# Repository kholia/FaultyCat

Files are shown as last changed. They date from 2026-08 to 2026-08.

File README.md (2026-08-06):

# Faulty Cat

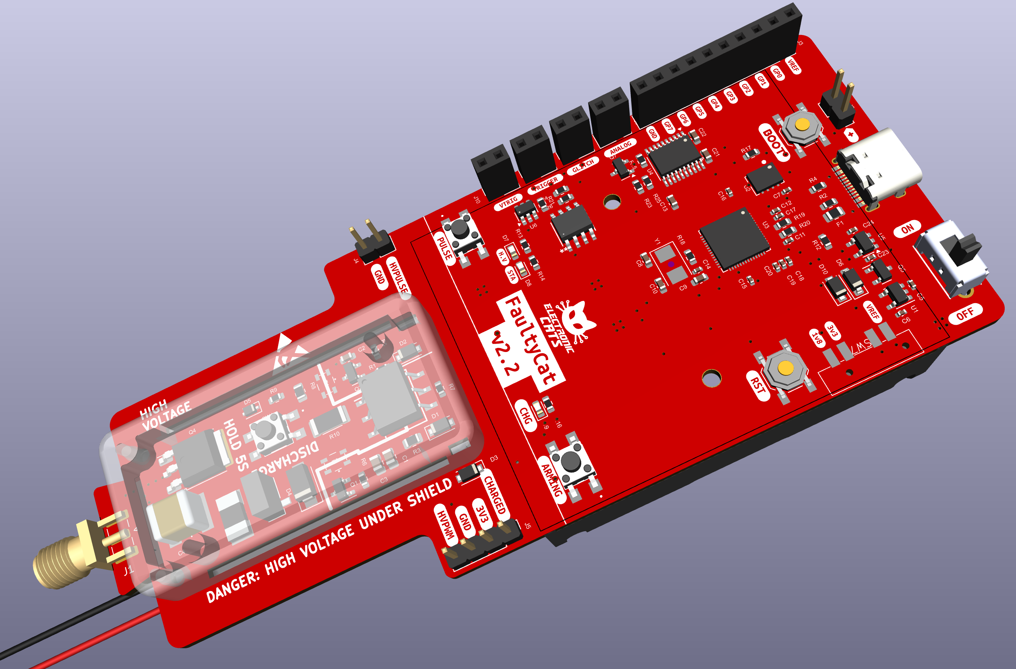
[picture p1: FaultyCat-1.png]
Fault Cat Render 1


> ## Firmware and host tools have moved
>
> This repository now holds the **hardware design** only. The
> firmware (v2, a from-scratch rewrite for the existing FaultyCat
> v2.x hardware) has moved to
> [FaultyCat-Firmware](https://github.com/ElectronicCats/FaultyCat-Firmware),
> and the Python host CLI/TUI (`faultycmd`) has moved to
> [faultycat-TUI](https://github.com/ElectronicCats/faultycat-TUI/).
> See the **Firmware Repository** and **Python Tools Repository**
> sections below.

Faulty Cat is a low-cost Electromagnetic Fault Injection (EMFI) tool, designed specifically for self-study and hobbiest research.

<a href="https://github.com/ElectronicCats/FaultyCat/wiki">
  <p align="center">
  
    </p>
</a>

<p align=center>
<a href="https://electroniccats.com/store/faulty-cat/">
  
</a>

<a href="https://github.com/ElectronicCats/faultycat/wiki">
  
</a>
</p>

<p align=center>
  Also available at distributors:
</p>
<p align=center>
  <a href="https://labs.ksec.co.uk/product-category/electronic-cat/">
    
  </a>
</p>

Faulty Cat is a high-end Electromagnetic Fault Injection (EMFI) tool a remix of the project [ChipSHOUTER PicoEMP](https://github.com/newaetech/chipshouter-picoemp) design optimization focused in rough order on (1) safe operation, (2) high performance, (3) usability, and finally (4) cost. This results in a tool that covers many use-cases, but may be overkill (and expensive) for many.

> **How the glitching works.** Firmware v3 ships two physical
> fault-injection techniques — **EMFI** (electromagnetic) and
> **Crowbar** (voltage glitching) — each available as **direct**
> single-shot fires or as parameter-swept **Campaigns**. For the
> full breakdown of what each engine does, the parameter matrix
> that differentiates them, and how the four combinations are
> driven from the host tool, see `docs/GLITCHING.md` in the
> [firmware repository](https://github.com/ElectronicCats/FaultyCat-Firmware).

We have created this project in KiCad and looking for alternatives to some components, we have left aside the Raspberry Pico board to use the RP2040 directly in the design. Tested in our laboratory before going on sale, even so, it is a product that must be handled with care, read the instructions for use.

Please **only** use Faulty Cat when you have purchased it from us and control it yourself, with full knowledge of the operation and risks. It is *not* designed for use in professional or educational environments, where tools are expected to meet safety certifications.

**IMPORTANT**: The plastic shield is critical for safe operation. While the output itself is isolated from the input connections, you will still **easily shock yourself** on the exposed high-voltage capacitor and circuitry. **NEVER** operate the device without the shield.

As an open-source project and as a remix of the project [ChipSHOUTER PicoEMP](https://github.com/newaetech/chipshouter-picoemp), it also collects inputs from various community members, and welcomes your contributions!

###  NEW FEATURES AVAILABLE ON V2.1⚡😼

- Voltage glitching.
- Trigger using dedicated pins, available in the new pinout.
- Trigger voltage reference, for more accurate response every time a voltage glitch is attempted to be sent.
- Analog input to monitor the target device’s status during the glitching process.
- JTAG/SWD scanner. **(Firmware v3.0 status: `scan swd` is the only
  scanner verb publicly exposed. JTAG scan, direct JTAG verbs, and
  direct SWD verbs are gated as WIP for v3.1 — see
  `docs/JTAG_INTERNALS.md` in the
  [firmware repository](https://github.com/ElectronicCats/FaultyCat-Firmware)
  for the details.)**

### Two attack engines (EMFI and Crowbar)

Firmware v3 exposes two physical fault-injection techniques (EMFI
and Crowbar voltage glitching) and two operational modes (direct
single-shot fires and Campaign parameter sweeps over delay/width/
power). They compose freely — both engines work in both modes.
The full matrix, wire-protocol routing, and host-CLI map live in
`docs/GLITCHING.md` in the
[firmware repository](https://github.com/ElectronicCats/FaultyCat-Firmware).

## Thanks / Contributors

Faulty Cat based in PicoEMP is a community-focused project, with major contributions from:
* Colin O'Flynn (original HW design, simple Python demo)
* [stacksmashing](https://twitter.com/ghidraninja) (C firmware for full PIO feature set)
* [Lennert Wouters](https://twitter.com/LennertWo) (C improvements, first real demo)
* [@nilswiersma](https://github.com/nilswiersma) (Triggering/C improvements)

## Firmware Repository

The FaultyCat firmware has been moved to a different repository, to
have a better version control, and issue tracking you will find it
here:

https://github.com/ElectronicCats/FaultyCat-Firmware

That repository covers building and flashing the firmware (BOOTSEL
button and magic-baud remote BOOTSEL paths), the release scheme, and
the full architecture / safety / glitching-engine documentation
(`docs/ARCHITECTURE.md`, `docs/SAFETY.md`, `docs/GLITCHING.md`,
`docs/JTAG_INTERNALS.md`, `docs/RELEASES.md`, etc.).

## Python Tools Repository

The `faultycmd` host CLI/TUI has been moved to a different
repository, to have a better version control, and issue tracking you
will find it here:

https://github.com/ElectronicCats/faultycat-TUI/

That repository covers installing and using `faultycmd` (venv setup
on Linux, Windows, macOS, hotkeys, trigger polarity, trigger
timeout).

### Useful References

If you don't know where to start with Electromagnetic Fault Injection (EMFI), you may find a couple of chapters of the [Hardware Hacking Handbook](https://nostarch.com/hardwarehacking) useful.

You can see a demo of PicoEMP being used on a real attack in this [TI CC SimpleLink attack demo](https://github.com/KULeuven-COSIC/SimpleLink-FI/blob/main/notebooks/5_ChipSHOUTER-PicoEMP.ipynb).

**WARNING**: The high voltage will be applied across the SMA connector. If an injection tip (coil) is present, it will absorb most of the power. If you leave the SMA connector open, you will present a high voltage pulse across this SMA and could shock yourself. Do NOT touch the output SMA tip as a general "best practice", and treat the output as if it has a high voltage present.

## How to contribute 
 Contributions are welcome!

Please read the document  [**Contribution Manual**](https://github.com/ElectronicCats/electroniccats-cla/blob/main/electroniccats-contribution-manual.md)  which will show you how to contribute your changes to the project.

✨ Thanks to all our [contributors](https://github.com/ElectronicCats/faultycat/graphs/contributors)! ✨

See [**_Electronic Cats CLA_**](https://github.com/ElectronicCats/electroniccats-cla/blob/main/electroniccats-cla.md) for more information.

See the  [**community code of conduct**](https://github.com/ElectronicCats/electroniccats-cla/blob/main/electroniccats-community-code-of-conduct.md) for a vision of the community we want to build and what we expect from it.

## License

This project FaultyCat is adapted from [ChipSHOUTER PicoEMP](https://github.com/newaetech/chipshouter-picoemp) by [Colin O'Flynn](https://github.com/colinoflynn) is licensed under CC BY-SA 3.0, "FaultyCat" contains modifications such as: porting the project to Kicad, modifying BOM and dimensions is licensed under CC BY-SA 3.0 by ElectronicCats.

Electronic Cats invests time and resources in providing this open-source design. Please support Electronic Cats and open-source hardware by purchasing products from Electronic Cats!

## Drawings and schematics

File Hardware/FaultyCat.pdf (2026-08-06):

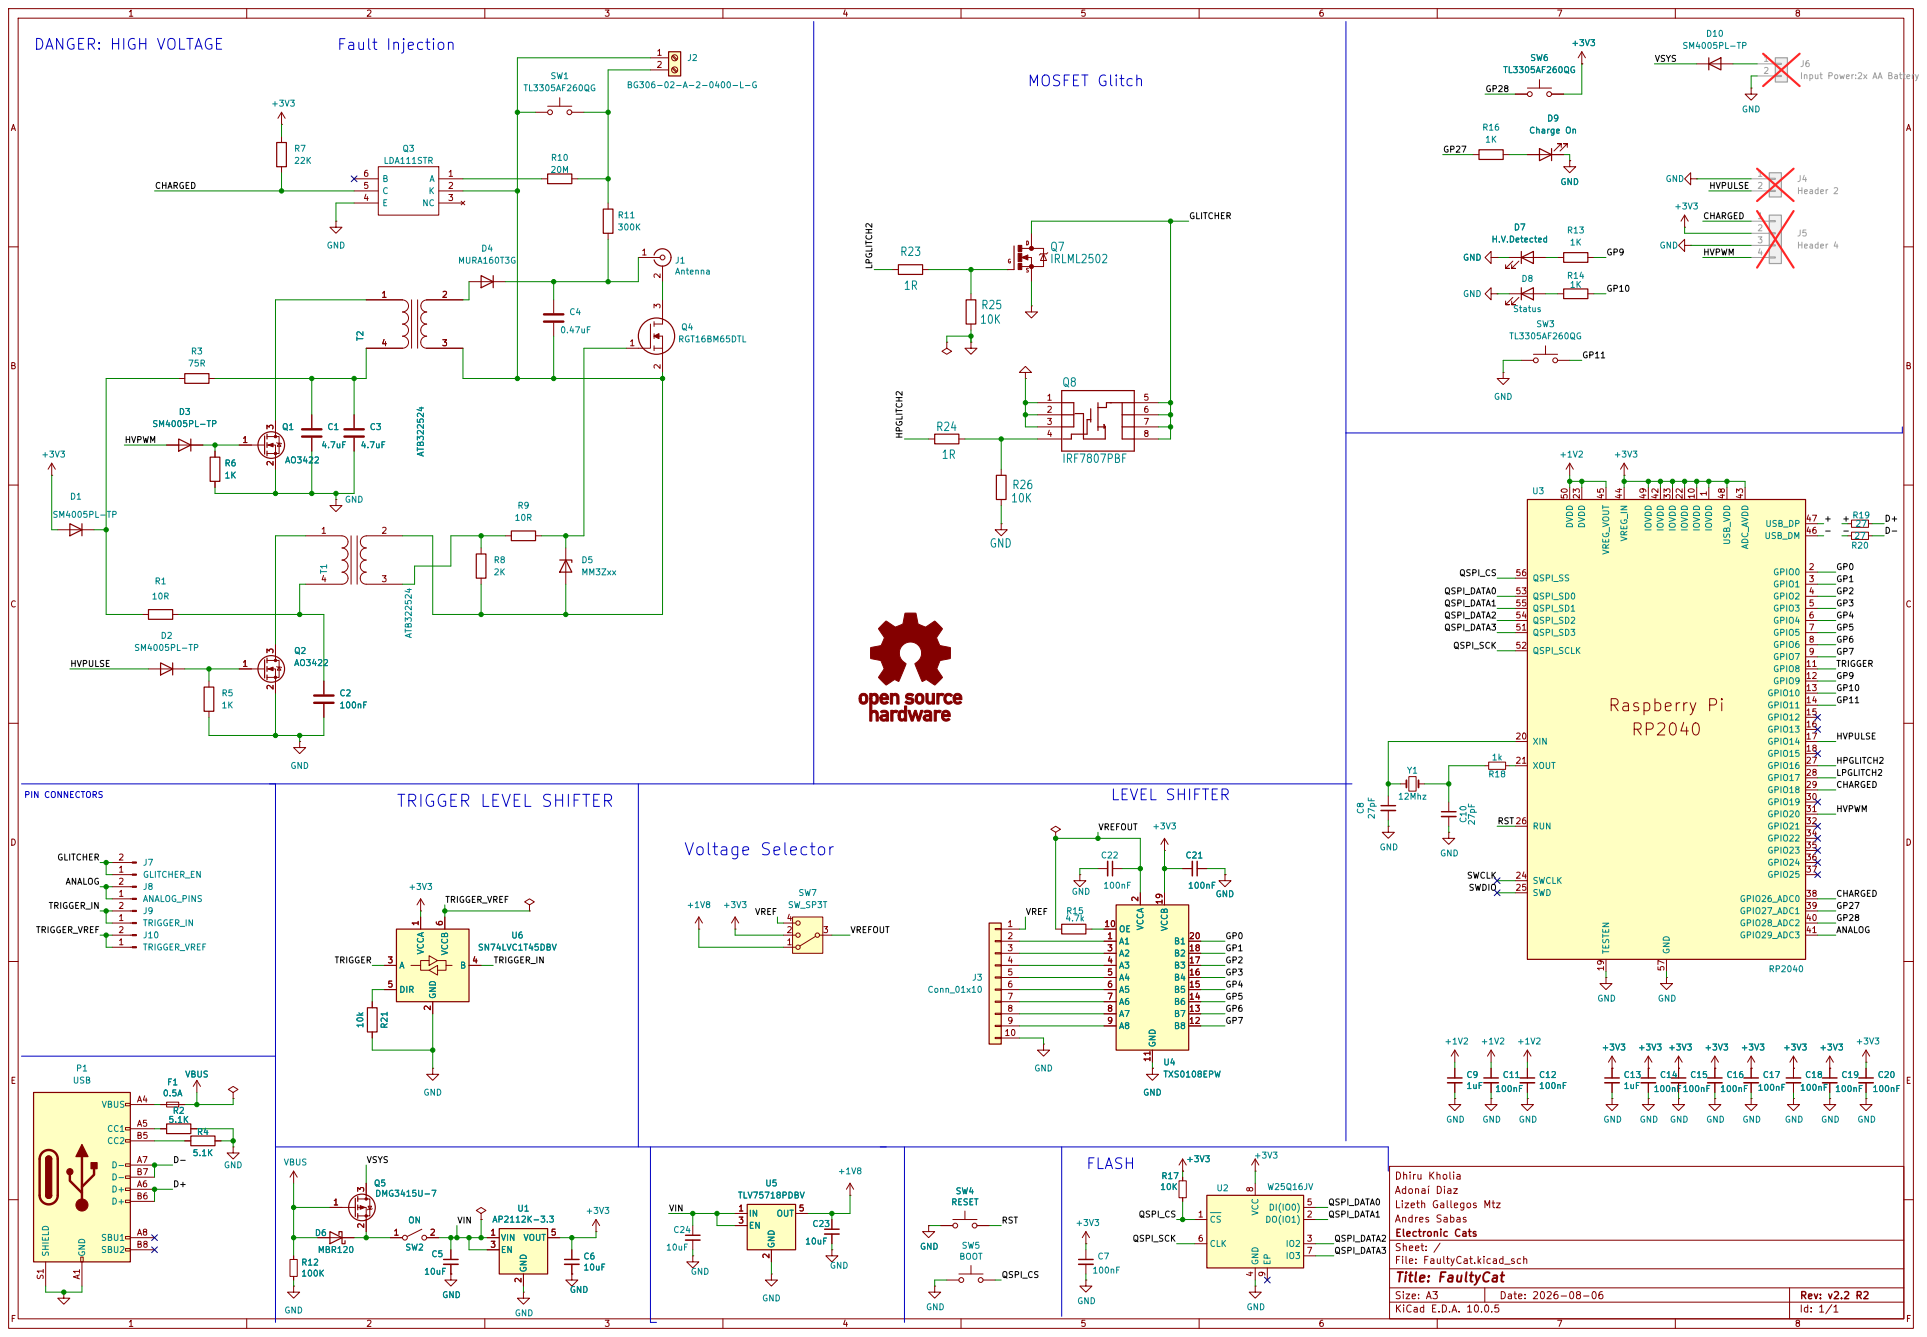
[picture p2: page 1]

Input Power:2x AA Battery

Size: A3 | Rev: v2.2 R2 | F Date: 2026-08-06
KiCad E.D.A. 10.0.5 | Id: 1/1

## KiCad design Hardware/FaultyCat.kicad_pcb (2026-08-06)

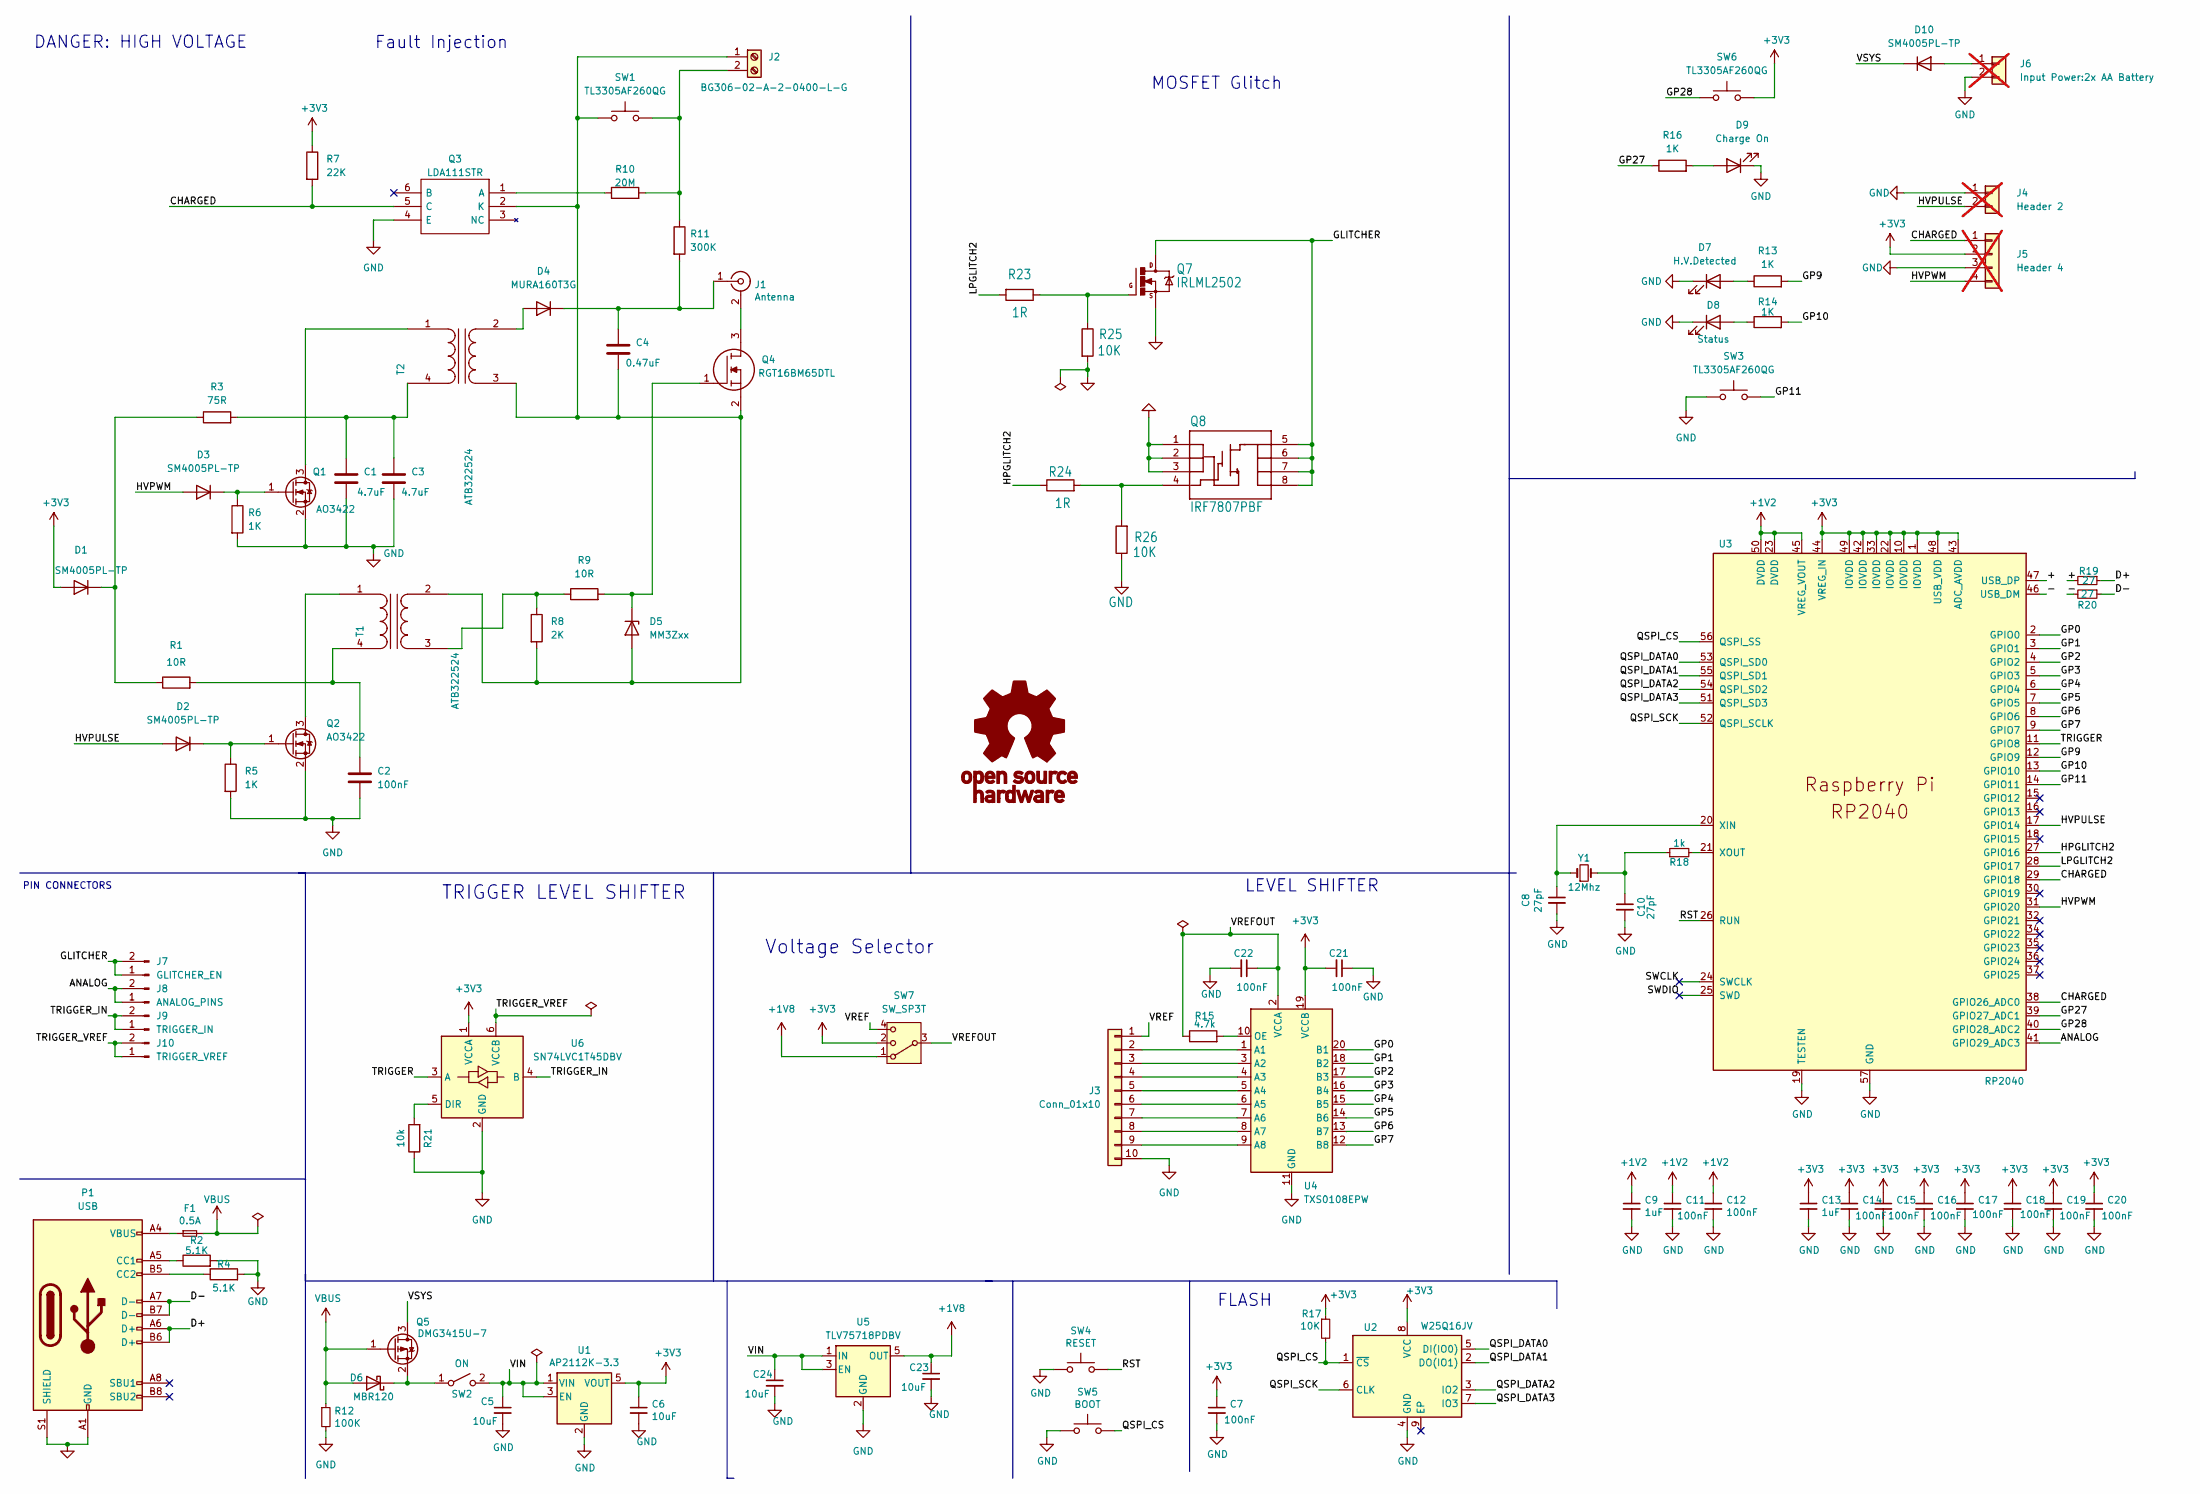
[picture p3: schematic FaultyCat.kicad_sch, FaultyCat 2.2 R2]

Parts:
C1, C3: 4.7uF; C_0805_2012Metric; LCSC# C98192
C2: 100nF; C_0603_1608Metric; LCSC# C30926
C4: 0.47uF; CAPC6153X500N; LCSC# C692326
C5, C6, C23, C24: 10uF; C_0402_1005Metric; LCSC# C15525
C7, C11, C12, C14, C15, C16, C17, C18, C19, C20: 100nF; C_0402_1005Metric; LCSC# C131394
C8, C10: 27pF; C_0603_1608Metric; LCSC# C107045
C9, C13: 1uF; C_0603_1608Metric; LCSC# C26413
C21, C22: 100nF; C_0603_1608Metric; LCSC# C14663
D1, D2, D3, D10: SM4005PL-TP; D_SOD-123F; LCSC# C437593
D4: MURA160T3G; D_SMA; LCSC# C85095
D5: MM3Zxx; D_SOD-323F; LCSC# C263147
D6: MBR120; D_SOD-123; LCSC# C130880
D7: H.V.Detected; LED_0603_1608Metric; LCSC# C157740
D8: Status; LED_0603_1608Metric; LCSC# C192666
D9: Charge On; LED_0603_1608Metric; LCSC# C157740
F1: 0.5A; Fuse_0805_2012Metric; LCSC# C2649565
J1: Antenna; SMA_Samtec_SMA-J-P-H-ST-EM1_EdgeMount
J2: BG306-02-A-2-0400-L-G; BG30602A20400LG
J3: Conn_01x10; PinSocket_1x10_P2.54mm_Vertical; LCSC# C5116489
J4: Header 2; PinHeader_1x02_P2.54mm_Vertical; not fitted
J5: Header 4; PinHeader_1x04_P2.54mm_Vertical; not fitted
J6: Input Power:2x AA Battery; PinHeader_1x02_P2.54mm_Vertical; not fitted
J7: GLITCHER_EN; PinSocket_1x02_P2.54mm_Vertical; LCSC# C7499322
J8: ANALOG_PINS; PinSocket_1x02_P2.54mm_Vertical; LCSC# C7499322
J9: TRIGGER_IN; PinSocket_1x02_P2.54mm_Vertical; LCSC# C7499322
J10: TRIGGER_VREF; PinSocket_1x02_P2.54mm_Vertical; LCSC# C7499322
P1: USB; USB_C_Receptacle_HRO_TYPE-C-31-M-12-Modded; LCSC C393939
PIC1: OSHW_Logo; OSHW-Logo_7.5x8mm_SilkScreen
Q1, Q2: AO3422; SOT-23; LCSC# C37130
Q3: LDA111STR; SOP254P952X470-6N
Q4: RGT16BM65DTL; TO-252-3_TabPin2; LCSC# C3193927
Q5: DMG3415U-7; SOT-23; LCSC# C96616
Q7: IRLML2502; SOT-23; LCSC# C5364308
Q8: IRF7807PBF; SOIC-8_SI; LCSC# C142600
R1, R9: 10R; R_0603_1608Metric; LCSC# C109318
R2, R4: 5.1K; R_0603_1608Metric; LCSC# C23186
R3: 75R; R_0805_2012Metric; LCSC# C141697
R5, R6, R13, R14, R16: 1K; R_0603_1608Metric; LCSC# C22548
R7: 22K; R_0603_1608Metric; LCSC# C114065
R8: 2K; R_0805_2012Metric; LCSC# C114572
R10: 20M; R_2010_5025Metric
R11: 300K; RESC6432X120N
R12: 100K; R_0603_1608Metric; LCSC# C100048
R15: 4.7k; R_0603_1608Metric; LCSC# C116697
R17, R25, R26: 10K; R_0603_1608Metric; LCSC# C103199
R18: 1k; R_0603_1608Metric; LCSC# C115325
R19, R20: 27; R_0603_1608Metric; LCSC# C25224
R21: 10k; R_0603_1608Metric; LCSC# C103199
R23, R24: 1R; R_0603_1608Metric; LCSC# C140111
SW1, SW3, SW6: TL3305AF260QG; TL3305AF160QG; LCSC# C2886902
SW2: ON; OS102011MA1QN1; LCSC# C221829
SW4: RESET; SW_SPST_TL3342; LCSC# C318889
SW5: BOOT; SW_SPST_TL3342; LCSC# C318889
SW7: SW_SP3T; Sw3P1T; LCSC# C361168
T1, T2: ATB322524; ATB3225240110T000; LCSC# C249001
U1: AP2112K-3.3; SOT-23-5; LCSC# C216640
U2: W25Q16JV; W25Q16JVUUIQ
U3: RP2040; RP2040-QFN-56; LCSC# C2040
U4: TXS0108EPW; TSSOP-20_4.4x6.5mm_P0.65mm; LCSC# C1021790
U5: TLV75718PDBV; SOT-23-5; LCSC# C507270
U6: SN74LVC1T45DBV; SOT-23-6; LCSC# C7843
Y1: 12Mhz; Crystal_SMD_5032-2Pin_5.0x3.2mm

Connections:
+1V2: C9.1, C11.1, C12.1, U3.23 (DVDD), U3.45 (VREG_VOUT), U3.50 (DVDD)
+1V8: C23.1, SW7.1, U5.5 (OUT)
+3V3: C6.1, C7.1, C13.1, C14.1, C15.1, C16.1, C17.1, C18.1, C19.1, C20.1, C21.2, D1.2 (A), J5.2, R7.1, R17.1, SW6.2, SW7.2, U1.5 (VOUT), U2.8 (VCC), U3.1 (IOVDD), U3.10 (IOVDD), U3.22 (IOVDD), U3.33 (IOVDD), U3.42 (IOVDD), U3.43 (ADC_AVDD), U3.44 (VREG_IN), U3.48 (USB_VDD), U3.49 (IOVDD), U4.19 (VCCB), U6.1 (VCCA)
/+: R19.2, U3.47 (USB_DP)
/-: R20.2, U3.46 (USB_DM)
/ANALOG: J8.1, J8.2, U3.41 (GPIO29_ADC3)
/CHARGED: J5.1, Q3.5 (C), R7.2, U3.29 (GPIO18), U3.38 (GPIO26_ADC0)
/D+: P1.A6 (D+), P1.B6 (D+), R19.1
/D-: P1.A7 (D-), P1.B7 (D-), R20.1
/GLITCHER: J7.1, J7.2, Q7.3 (D), Q8.5 (D@4), Q8.6 (D@3), Q8.7 (D@2), Q8.8 (D@1)
/GP0: U3.2 (GPIO0), U4.20 (B1)
/GP1: U3.3 (GPIO1), U4.18 (B2)
/GP2: U3.4 (GPIO2), U4.17 (B3)
/GP3: U3.5 (GPIO3), U4.16 (B4)
/GP4: U3.6 (GPIO4), U4.15 (B5)
/GP5: U3.7 (GPIO5), U4.14 (B6)
/GP6: U3.8 (GPIO6), U4.13 (B7)
/GP7: U3.9 (GPIO7), U4.12 (B8)
/GP9: R13.2, U3.12 (GPIO9)
/GP10: R14.2, U3.13 (GPIO10)
/GP11: SW3.2, U3.14 (GPIO11)
/GP27: R16.1, U3.39 (GPIO27_ADC1)
/GP28: SW6.1, U3.40 (GPIO28_ADC2)
/HPGLITCH2: R24.1, U3.27 (GPIO16)
/HVPULSE: D2.2 (A), J4.2, U3.17 (GPIO14)
/HVPWM: D3.2 (A), J5.4, U3.31 (GPIO20)
/LPGLITCH2: R23.2, U3.28 (GPIO17)
/QSPI_CS: R17.2, SW5.2, U2.1 (~CS), U3.56 (QSPI_SS)
/QSPI_DATA0: U2.5 (DI(IO0)), U3.53 (QSPI_SD0)
/QSPI_DATA1: U2.2 (DO(IO1)), U3.55 (QSPI_SD1)
/QSPI_DATA2: U2.3 (IO2), U3.54 (QSPI_SD2)
/QSPI_DATA3: U2.7 (IO3), U3.51 (QSPI_SD3)
/QSPI_SCK: U2.6 (CLK), U3.52 (QSPI_SCLK)
/RST: SW4.2, U3.26 (RUN)
/SWCLK: U3.24 (SWCLK)
/SWDIO: U3.25 (SWD)
/TRIGGER: U3.11 (GPIO8), U6.3 (A)
/TRIGGER_IN: J9.1, J9.2, U6.4 (B)
/TRIGGER_VREF: J10.1, J10.2, U6.6 (VCCB)
/VIN: C5.1, C24.1, SW2.2 (B), U1.1 (VIN), U1.3 (EN), U5.1 (IN), U5.3 (EN)
/VREF: J3.1, SW7.4
/VREFOUT: C22.1, R15.1, SW7.3, U4.2 (VCCA)
/VSYS: D10.1 (K), Q5.3 (D)
GND: C1.2, C2.2, C3.2, C5.2, C6.2, C7.2, C8.2, C9.2, C10.2, C11.2, C12.2, C13.2, C14.2, C15.2, C16.2, C17.2, C18.2, C19.2, C20.2, C21.1, C22.2, C23.2, C24.2, D7.1 (K), D8.1 (K), D9.1 (K), J3.10, J4.1, J5.3, J6.2, P1.A1 (GND), P1.A12 (GND), P1.B1 (GND), P1.B12 (GND), P1.S1 (SHIELD), Q1.2 (S), Q2.2 (S), Q3.4 (E), Q7.2 (S), Q8.1 (S@1), Q8.2 (S@2), Q8.3 (S@3), R2.2, R4.2, R5.2, R6.2, R12.2, R21.1, R25.2, R26.1, SW3.1, SW4.1, SW5.1, U1.2 (GND), U2.4 (GND), U3.19 (TESTEN), U3.57 (GND), U4.11 (GND), U5.2 (GND), U6.2 (GND)
unnamed: C10.1, R18.1, Y1.2
unnamed: D1.1 (K), R1.1, R3.1
unnamed: D2.1 (K), Q2.1 (G), R5.1
unnamed: D3.1 (K), Q1.1 (G), R6.1
unnamed: D4.2 (A), T2.2 (SA)
unnamed: C4.1, D4.1 (K), J1.1 (In), R11.2
unnamed: C4.2, D5.2 (A), J2.1, Q3.2 (K), Q4.2, R8.2, SW1.1, T1.2 (SA), T2.3 (SB)
unnamed: D5.1 (K), Q4.1, R9.2
unnamed: D6.1 (K), Q5.2 (S), SW2.1 (A)
unnamed: D7.2 (A), R13.1
unnamed: D8.2 (A), R14.1
unnamed: D9.2 (A), R16.2
unnamed: D10.2 (A), J6.1
unnamed: F1.1, P1.A4 (VBUS), P1.A9 (VBUS), P1.B4 (VBUS), P1.B9 (VBUS)
unnamed: J1.2 (Ext), Q4.3
unnamed: J2.2, R10.2, R11.1, SW1.2
unnamed: J3.2, U4.1 (A1)
unnamed: J3.3, U4.3 (A2)
unnamed: J3.4, U4.4 (A3)
unnamed: J3.5, U4.5 (A4)
unnamed: J3.6, U4.6 (A5)
unnamed: J3.7, U4.7 (A6)
unnamed: J3.8, U4.8 (A7)
unnamed: J3.9, U4.9 (A8)
unnamed: P1.A5 (CC1), R2.1
unnamed: P1.B5 (CC2), R4.1
unnamed: Q1.3 (D), T2.1 (AB)
unnamed: Q2.3 (D), T1.1 (AB)
unnamed: Q3.1 (A), R10.1
unnamed: Q7.1 (G), R23.1, R25.1
unnamed: Q8.4 (G), R24.2, R26.2
unnamed: C2.1, R1.2, T1.4 (AA)
unnamed: R8.1, R9.1, T1.3 (SB)
unnamed: C1.1, C3.1, R3.2, T2.4 (AA)
unnamed: C8.1, U3.20 (XIN), Y1.1
unnamed: R18.2, U3.21 (XOUT)
unnamed: R15.2, U4.10 (OE)
unnamed: R21.2, U6.5 (DIR)
VBUS: D6.2 (A), F1.2, Q5.1 (G), R12.1

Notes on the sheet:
Voltage Selector
FLASH
TRIGGER LEVEL SHIFTER
MOSFET Glitch
DANGER: HIGH VOLTAGE
PIN CONNECTORS
LEVEL SHIFTER
Fault Injection

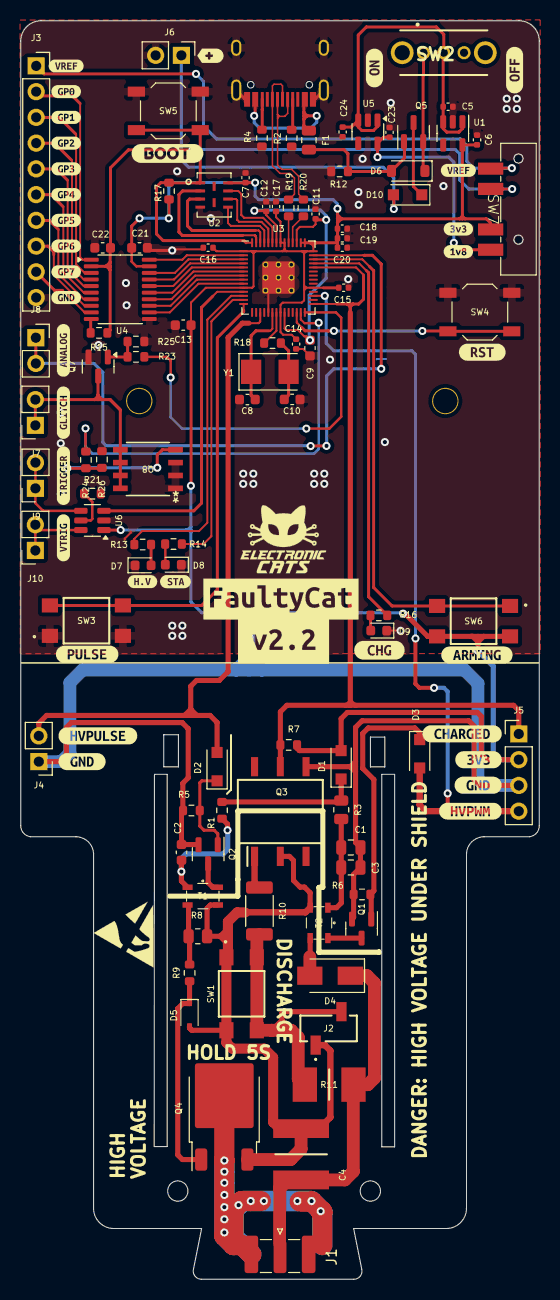
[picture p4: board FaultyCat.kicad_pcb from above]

Board: 2 copper layers, 51.2 x 124.2 mm, 133 parts (1 on the bottom side), 81 nets.

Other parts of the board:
HOLE1: BatteryHolder
HOLE3, HOLE4: (no value)
kibuzzard-67A4D63C: G***; kibuzzard-67A4D63C
kibuzzard-67A4D65E: G***; kibuzzard-67A4D65E
kibuzzard-67A4D80D: G***; kibuzzard-67A4D80D
kibuzzard-67A4D86D: G***; kibuzzard-67A4D86D
kibuzzard-67A4D88F: G***; kibuzzard-67A4D88F
kibuzzard-67A4D93E: G***; kibuzzard-67A4D93E
kibuzzard-67A4D642: G***; kibuzzard-67A4D642
kibuzzard-67A4D648: G***; kibuzzard-67A4D648
kibuzzard-67A4D805: G***; kibuzzard-67A4D805
kibuzzard-67A4D873: G***; kibuzzard-67A4D873
kibuzzard-67A4D879: G***; kibuzzard-67A4D879
kibuzzard-67A4D880: G***; kibuzzard-67A4D880
kibuzzard-67A4D886: G***; kibuzzard-67A4D886
kibuzzard-67A4D896: G***; kibuzzard-67A4D896
kibuzzard-67AA52CA: G***; kibuzzard-67AA52CA
kibuzzard-67AA52D2: G***; kibuzzard-67AA52D2
kibuzzard-69BAD4E7: G***; kibuzzard-69BAD4E7
kibuzzard-642DF5C4: G***; kibuzzard-642DF5C4
kibuzzard-642DF578: G***; kibuzzard-642DF578
kibuzzard-642E0AC9: G***; kibuzzard-642E0AC9
kibuzzard-642E0AD5: G***; kibuzzard-642E0AD5
kibuzzard-642E0AF5: G***; kibuzzard-642E0AF5
kibuzzard-642E0B26: G***; kibuzzard-642E0B26
kibuzzard-642E0B82: G***; kibuzzard-642E0B82
kibuzzard-642E0B91: G***; kibuzzard-642E0B91
kibuzzard-642E11AF: G***; kibuzzard-642E11AF
kibuzzard-642F0B74: G***; kibuzzard-642F0B74
kibuzzard-681E47A0: G***; kibuzzard-681E47A0
kibuzzard-681E47A5: G***; kibuzzard-681E47A5
kibuzzard-681E4798: G***; kibuzzard-681E4798
kibuzzard-6797D18C: G***; kibuzzard-6797D18C
kibuzzard-64767B55: G***; kibuzzard-64767B55
kibuzzard-647546A8: G***; kibuzzard-647546A8
kibuzzard-647546B9: G***; kibuzzard-647546B9
kibuzzard-6475468D: G***; kibuzzard-6475468D

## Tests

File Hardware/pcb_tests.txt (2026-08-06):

# Exhaustive pad-to-net assertions for FaultyCat.kicad_pcb
#
# Generated from the PCB by `make extract-pcb-tests`.
# Verify that it is current with `make verify-pcb-tests`.
# Run the assertions with `make pcb-tests`.
#
# Extraction baseline:
#   - 136 total footprint objects
#   - 94 annotated electrical footprints
#   - 349 physical pads on those footprints
#   - 320 distinct REF:PAD assertions
#   - 10 pads excluded because their footprint or pad is unannotated
#
# Repeated physical pads sharing one pad number produce one assertion. Exact
# autogenerated Net-(...) names are intentional; only a true pad with no net
# is written as <no-net>.
#
# This proves assigned PCB pad/net topology. It does not prove component
# values, electrical limits, signal integrity, power sequencing, assembly
# quality, or safe target behavior.

C1:1=Net-(T2-AA)
C1:2=GND

C2:1=Net-(T1-AA)
C2:2=GND

C3:1=Net-(T2-AA)
C3:2=GND

C4:1=Net-(D4-K)
C4:2=Net-(D5-A)

C5:1=/VIN
C5:2=GND

C6:1=+3V3
C6:2=GND

C7:1=+3V3
C7:2=GND

C8:1=Net-(U3-XIN)
C8:2=GND

C9:1=+1V2
C9:2=GND

C10:1=Net-(C10-Pad1)
C10:2=GND

C11:1=+1V2
C11:2=GND

C12:1=+1V2
C12:2=GND

C13:1=+3V3
C13:2=GND

C14:1=+3V3
C14:2=GND

C15:1=+3V3
C15:2=GND

C16:1=+3V3
C16:2=GND

C17:1=+3V3
C17:2=GND

C18:1=+3V3
C18:2=GND

C19:1=+3V3
C19:2=GND

C20:1=+3V3
C20:2=GND

C21:1=GND
C21:2=+3V3

C22:1=/VREFOUT
C22:2=GND

C23:1=+1V8
C23:2=GND

C24:1=/VIN
C24:2=GND

D1:1=Net-(D1-K)
D1:2=+3V3

D2:1=Net-(D2-K)
D2:2=/HVPULSE

D3:1=Net-(D3-K)
D3:2=/HVPWM

D4:1=Net-(D4-K)
D4:2=Net-(D4-A)

D5:1=Net-(D5-K)
D5:2=Net-(D5-A)

D6:1=Net-(D6-K)
D6:2=VBUS

D7:1=GND
D7:2=Net-(D7-A)

D8:1=GND
D8:2=Net-(D8-A)

D9:1=GND
D9:2=Net-(D9-A)

D10:1=/VSYS
D10:2=Net-(D10-A)

F1:1=Net-(F1-Pad1)
F1:2=VBUS

J1:1=Net-(D4-K)
J1:2=Net-(J1-Ext)

J2:1=Net-(D5-A)
J2:2=Net-(J2-Pin_2)

J3:1=/VREF
J3:2=Net-(J3-Pin_2)
J3:3=Net-(J3-Pin_3)
J3:4=Net-(J3-Pin_4)
J3:5=Net-(J3-Pin_5)
J3:6=Net-(J3-Pin_6)
J3:7=Net-(J3-Pin_7)
J3:8=Net-(J3-Pin_8)
J3:9=Net-(J3-Pin_9)
J3:10=GND

J4:1=GND
J4:2=/HVPULSE

J5:1=/CHARGED
J5:2=+3V3
J5:3=GND
J5:4=/HVPWM

J6:1=Net-(D10-A)
J6:2=GND

J7:1=/GLITCHER
J7:2=/GLITCHER

J8:1=/ANALOG
J8:2=/ANALOG

J9:1=/TRIGGER_IN
J9:2=/TRIGGER_IN

J10:1=/TRIGGER_VREF
J10:2=/TRIGGER_VREF

P1:A1=GND
P1:A4=Net-(F1-Pad1)
P1:A5=Net-(P1-CC)
P1:A6=/D+
P1:A7=/D-
P1:A8=<no-net>
P1:B5=Net-(P1-VCONN)
P1:B8=<no-net>
P1:S1=GND

Q1:1=Net-(D3-K)
Q1:2=GND
Q1:3=Net-(Q1-D)

Q2:1=Net-(D2-K)
Q2:2=GND
Q2:3=Net-(Q2-D)

Q3:1=Net-(Q3-A)
Q3:2=Net-(D5-A)
Q3:3=unconnected-(Q3-NC-Pad3)
Q3:4=GND
Q3:5=/CHARGED
Q3:6=unconnected-(Q3-B-Pad6)

Q4:1=Net-(D5-K)
Q4:2=Net-(D5-A)
Q4:3=Net-(J1-Ext)

Q5:1=VBUS
Q5:2=Net-(D6-K)
Q5:3=/VSYS

Q7:1=Net-(Q7-G)
Q7:2=GND
Q7:3=/GLITCHER

Q8:1=GND
Q8:2=GND
Q8:3=GND
Q8:4=Net-(Q8-G)
Q8:5=/GLITCHER
Q8:6=/GLITCHER
Q8:7=/GLITCHER
Q8:8=/GLITCHER

R1:1=Net-(D1-K)
R1:2=Net-(T1-AA)

R2:1=Net-(P1-CC)
R2:2=GND

R3:1=Net-(D1-K)
R3:2=Net-(T2-AA)

R4:1=Net-(P1-VCONN)
R4:2=GND

R5:1=Net-(D2-K)
R5:2=GND

R6:1=Net-(D3-K)
R6:2=GND

R7:1=+3V3
R7:2=/CHARGED

R8:1=Net-(T1-SB)
R8:2=Net-(D5-A)

R9:1=Net-(T1-SB)
R9:2=Net-(D5-K)

R10:1=Net-(Q3-A)
R10:2=Net-(J2-Pin_2)

R11:1=Net-(J2-Pin_2)
R11:2=Net-(D4-K)

R12:1=VBUS
R12:2=GND

R13:1=Net-(D7-A)
R13:2=/GP9

R14:1=Net-(D8-A)
R14:2=/GP10

R15:1=/VREFOUT
R15:2=Net-(U4-OE)

R16:1=/GP27
R16:2=Net-(D9-A)

R17:1=+3V3
R17:2=/QSPI_CS

R18:1=Net-(C10-Pad1)
R18:2=Net-(U3-XOUT)

R19:1=/D+
R19:2=/+

R20:1=/D-
R20:2=/-

R21:1=GND
R21:2=Net-(U6-DIR)

R23:1=Net-(Q7-G)
R23:2=/LPGLITCH2

R24:1=/HPGLITCH2
R24:2=Net-(Q8-G)

R25:1=Net-(Q7-G)
R25:2=GND

R26:1=GND
R26:2=Net-(Q8-G)

SW1:1=Net-(D5-A)
SW1:2=Net-(J2-Pin_2)

SW2:1=Net-(D6-K)
SW2:2=/VIN
SW2:3=<no-net>
SW2:4=<no-net>
SW2:5=<no-net>

SW3:1=GND
SW3:2=/GP11

SW4:1=GND
SW4:2=/RST

SW5:1=GND
SW5:2=/QSPI_CS

SW6:1=/GP28
SW6:2=+3V3

SW7:1=+1V8
SW7:2=+3V3
SW7:3=/VREFOUT
SW7:4=/VREF

T1:1=Net-(Q2-D)
T1:2=Net-(D5-A)
T1:3=Net-(T1-SB)
T1:4=Net-(T1-AA)

T2:1=Net-(Q1-D)
T2:2=Net-(D4-A)
T2:3=Net-(D5-A)
T2:4=Net-(T2-AA)

U1:1=/VIN
U1:2=GND
U1:3=/VIN
U1:4=unconnected-(U1-NC-Pad4)
U1:5=+3V3

U2:1=/QSPI_CS
U2:2=/QSPI_DATA1
U2:3=/QSPI_DATA2
U2:4=GND
U2:5=/QSPI_DATA0
U2:6=/QSPI_SCK
U2:7=/QSPI_DATA3
U2:8=+3V3
U2:9=unconnected-(U2-EP-Pad9)
U2:10=<no-net>

U3:1=+3V3
U3:2=/GP0
U3:3=/GP1
U3:4=/GP2
U3:5=/GP3
U3:6=/GP4
U3:7=/GP5
U3:8=/GP6
U3:9=/GP7
U3:10=+3V3
U3:11=/TRIGGER
U3:12=/GP9
U3:13=/GP10
U3:14=/GP11
U3:15=unconnected-(U3-GPIO12-Pad15)
U3:16=unconnected-(U3-GPIO13-Pad16)
U3:17=/HVPULSE
U3:18=unconnected-(U3-GPIO15-Pad18)
U3:19=GND
U3:20=Net-(U3-XIN)
U3:21=Net-(U3-XOUT)
U3:22=+3V3
U3:23=+1V2
U3:24=/SWCLK
U3:25=/SWDIO
U3:26=/RST
U3:27=/HPGLITCH2
U3:28=/LPGLITCH2
U3:29=/CHARGED
U3:30=unconnected-(U3-GPIO19-Pad30)
U3:31=/HVPWM
U3:32=unconnected-(U3-GPIO21-Pad32)
U3:33=+3V3
U3:34=unconnected-(U3-GPIO22-Pad34)
U3:35=unconnected-(U3-GPIO23-Pad35)
U3:36=unconnected-(U3-GPIO24-Pad36)
U3:37=unconnected-(U3-GPIO25-Pad37)
U3:38=/CHARGED
U3:39=/GP27
U3:40=/GP28
U3:41=/ANALOG
U3:42=+3V3
U3:43=+3V3
U3:44=+3V3
U3:45=+1V2
U3:46=/-
U3:47=/+
U3:48=+3V3
U3:49=+3V3
U3:50=+1V2
U3:51=/QSPI_DATA3
U3:52=/QSPI_SCK
U3:53=/QSPI_DATA0
U3:54=/QSPI_DATA2
U3:55=/QSPI_DATA1
U3:56=/QSPI_CS
U3:57=GND

U4:1=Net-(J3-Pin_2)
U4:2=/VREFOUT
U4:3=Net-(J3-Pin_3)
U4:4=Net-(J3-Pin_4)
U4:5=Net-(J3-Pin_5)
U4:6=Net-(J3-Pin_6)
U4:7=Net-(J3-Pin_7)
U4:8=Net-(J3-Pin_8)
U4:9=Net-(J3-Pin_9)
U4:10=Net-(U4-OE)
U4:11=GND
U4:12=/GP7
U4:13=/GP6
U4:14=/GP5
U4:15=/GP4
U4:16=/GP3
U4:17=/GP2
U4:18=/GP1
U4:19=+3V3
U4:20=/GP0

U5:1=/VIN
U5:2=GND
U5:3=/VIN
U5:4=unconnected-(U5-NC-Pad4)
U5:5=+1V8

U6:1=+3V3
U6:2=GND
U6:3=/TRIGGER
U6:4=/TRIGGER_IN
U6:5=Net-(U6-DIR)
U6:6=/TRIGGER_VREF

Y1:1=Net-(U3-XIN)
Y1:2=Net-(C10-Pad1)
